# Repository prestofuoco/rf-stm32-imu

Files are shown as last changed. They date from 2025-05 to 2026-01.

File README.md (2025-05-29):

# rf-stm32-imu
4-layer (sig-gnd-gnd-sig) PCB with STM32F4, ICM20948, NRF24L01, USB-C, and 2.4GHz PCB trace antenna from TI's AN043. USB and RF traces are impedance matched/controlled to 90 ohms and 50 ohms respectively.

Antenna: https://www.ti.com/lit/an/swra117d/swra117d.pdf
<p align="center">
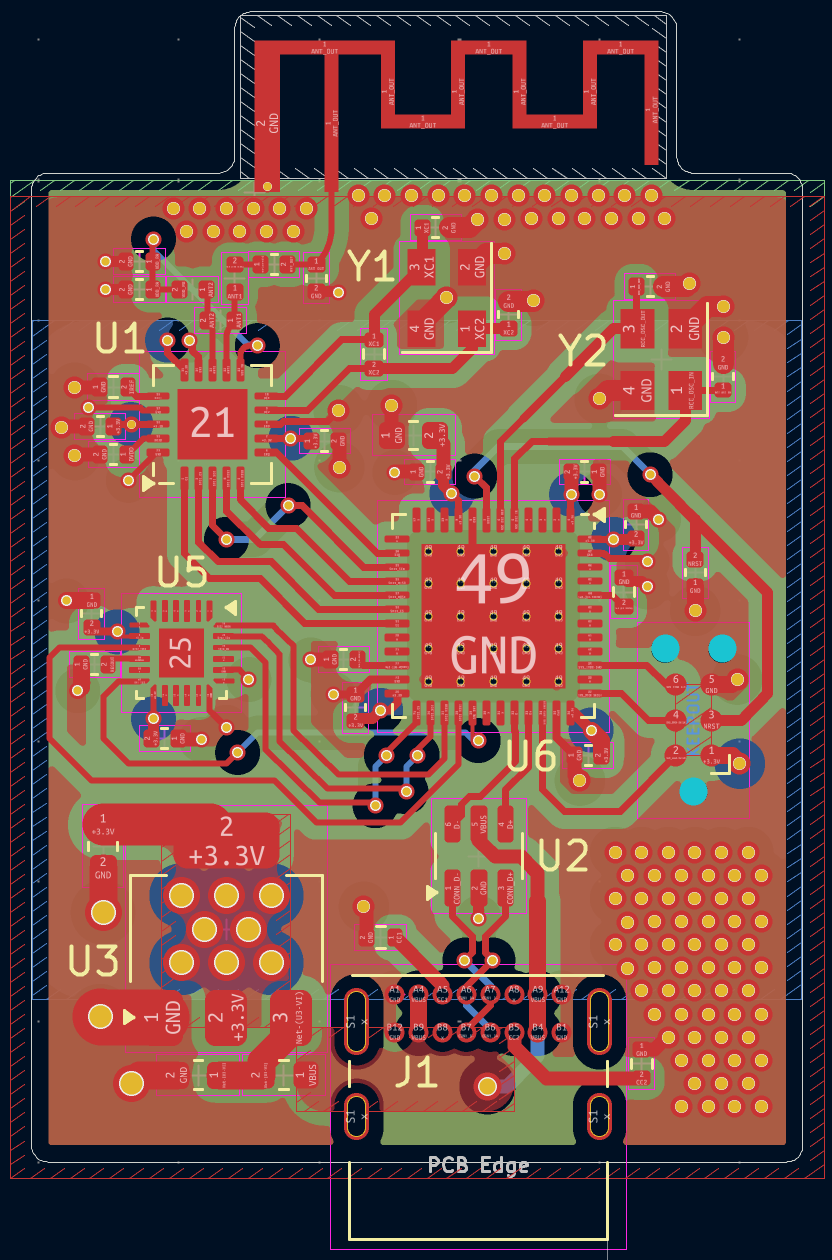
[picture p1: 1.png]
  
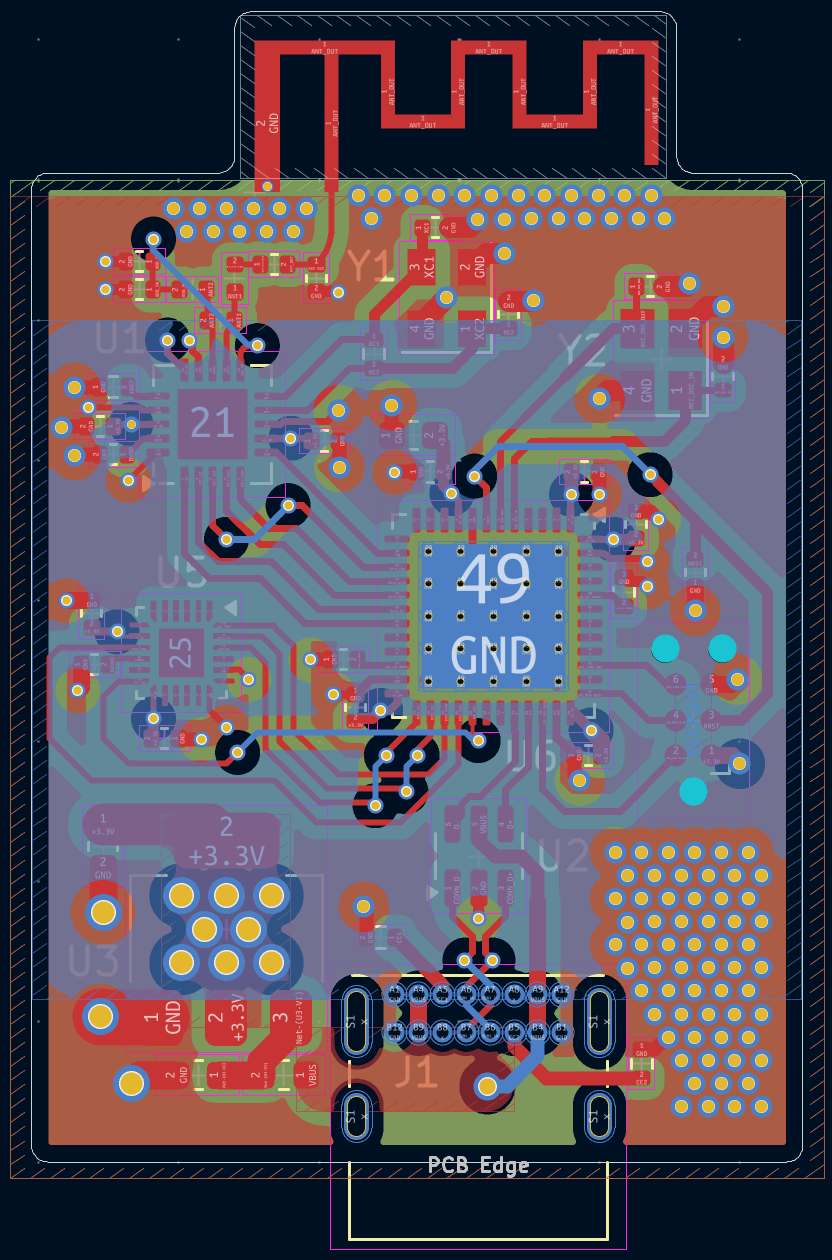
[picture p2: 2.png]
  
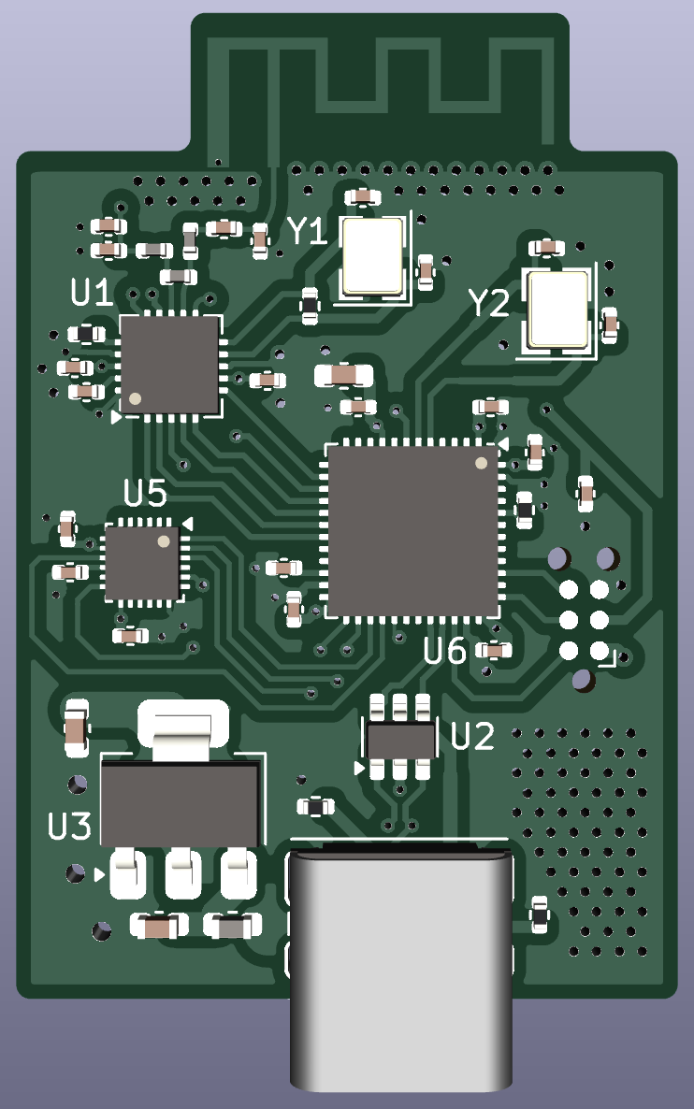
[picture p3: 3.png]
  
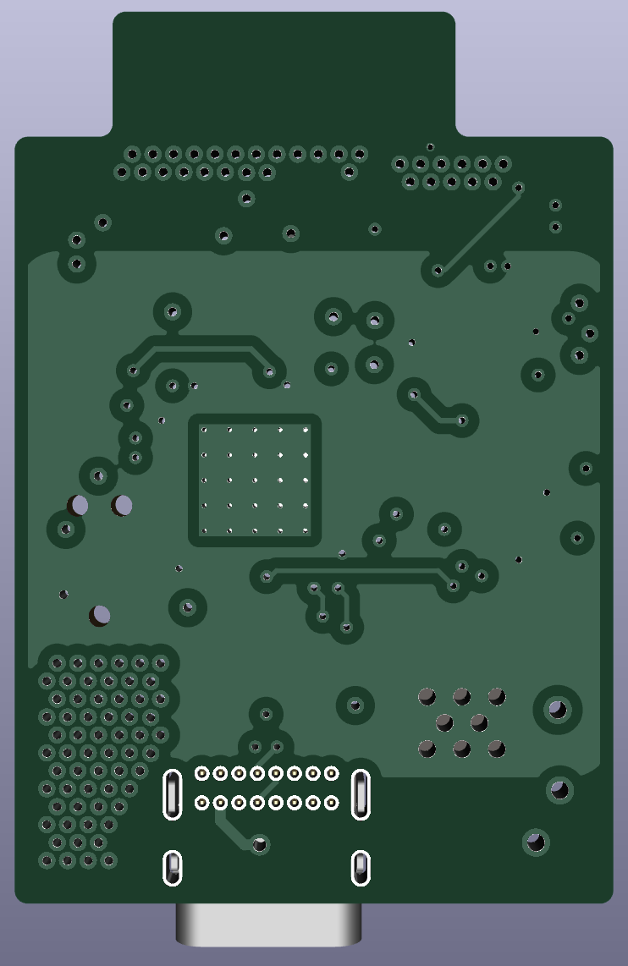
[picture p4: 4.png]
  
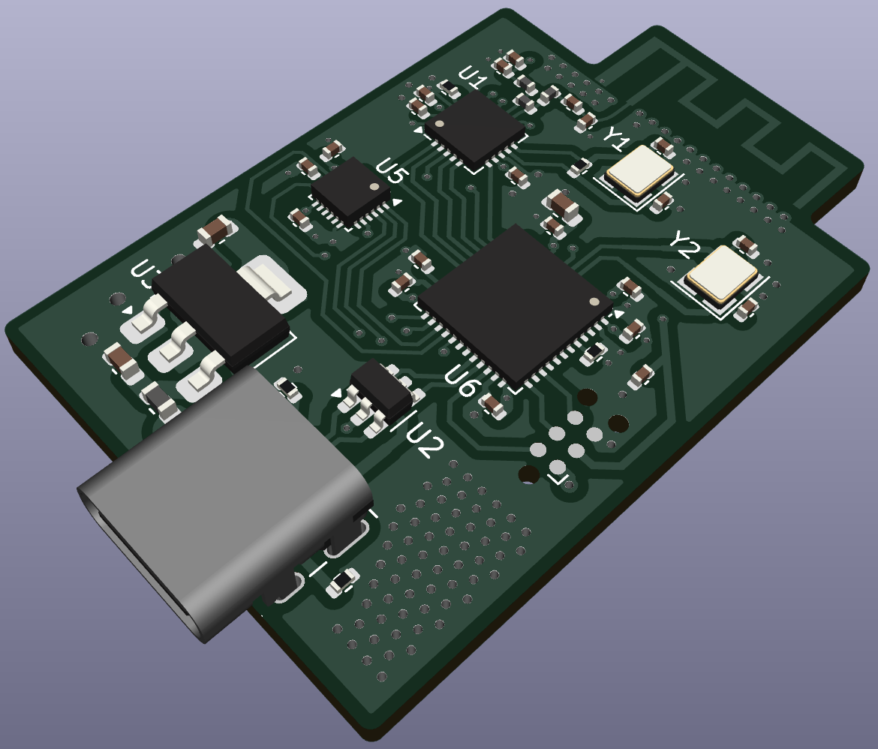
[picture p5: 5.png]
  
</p>

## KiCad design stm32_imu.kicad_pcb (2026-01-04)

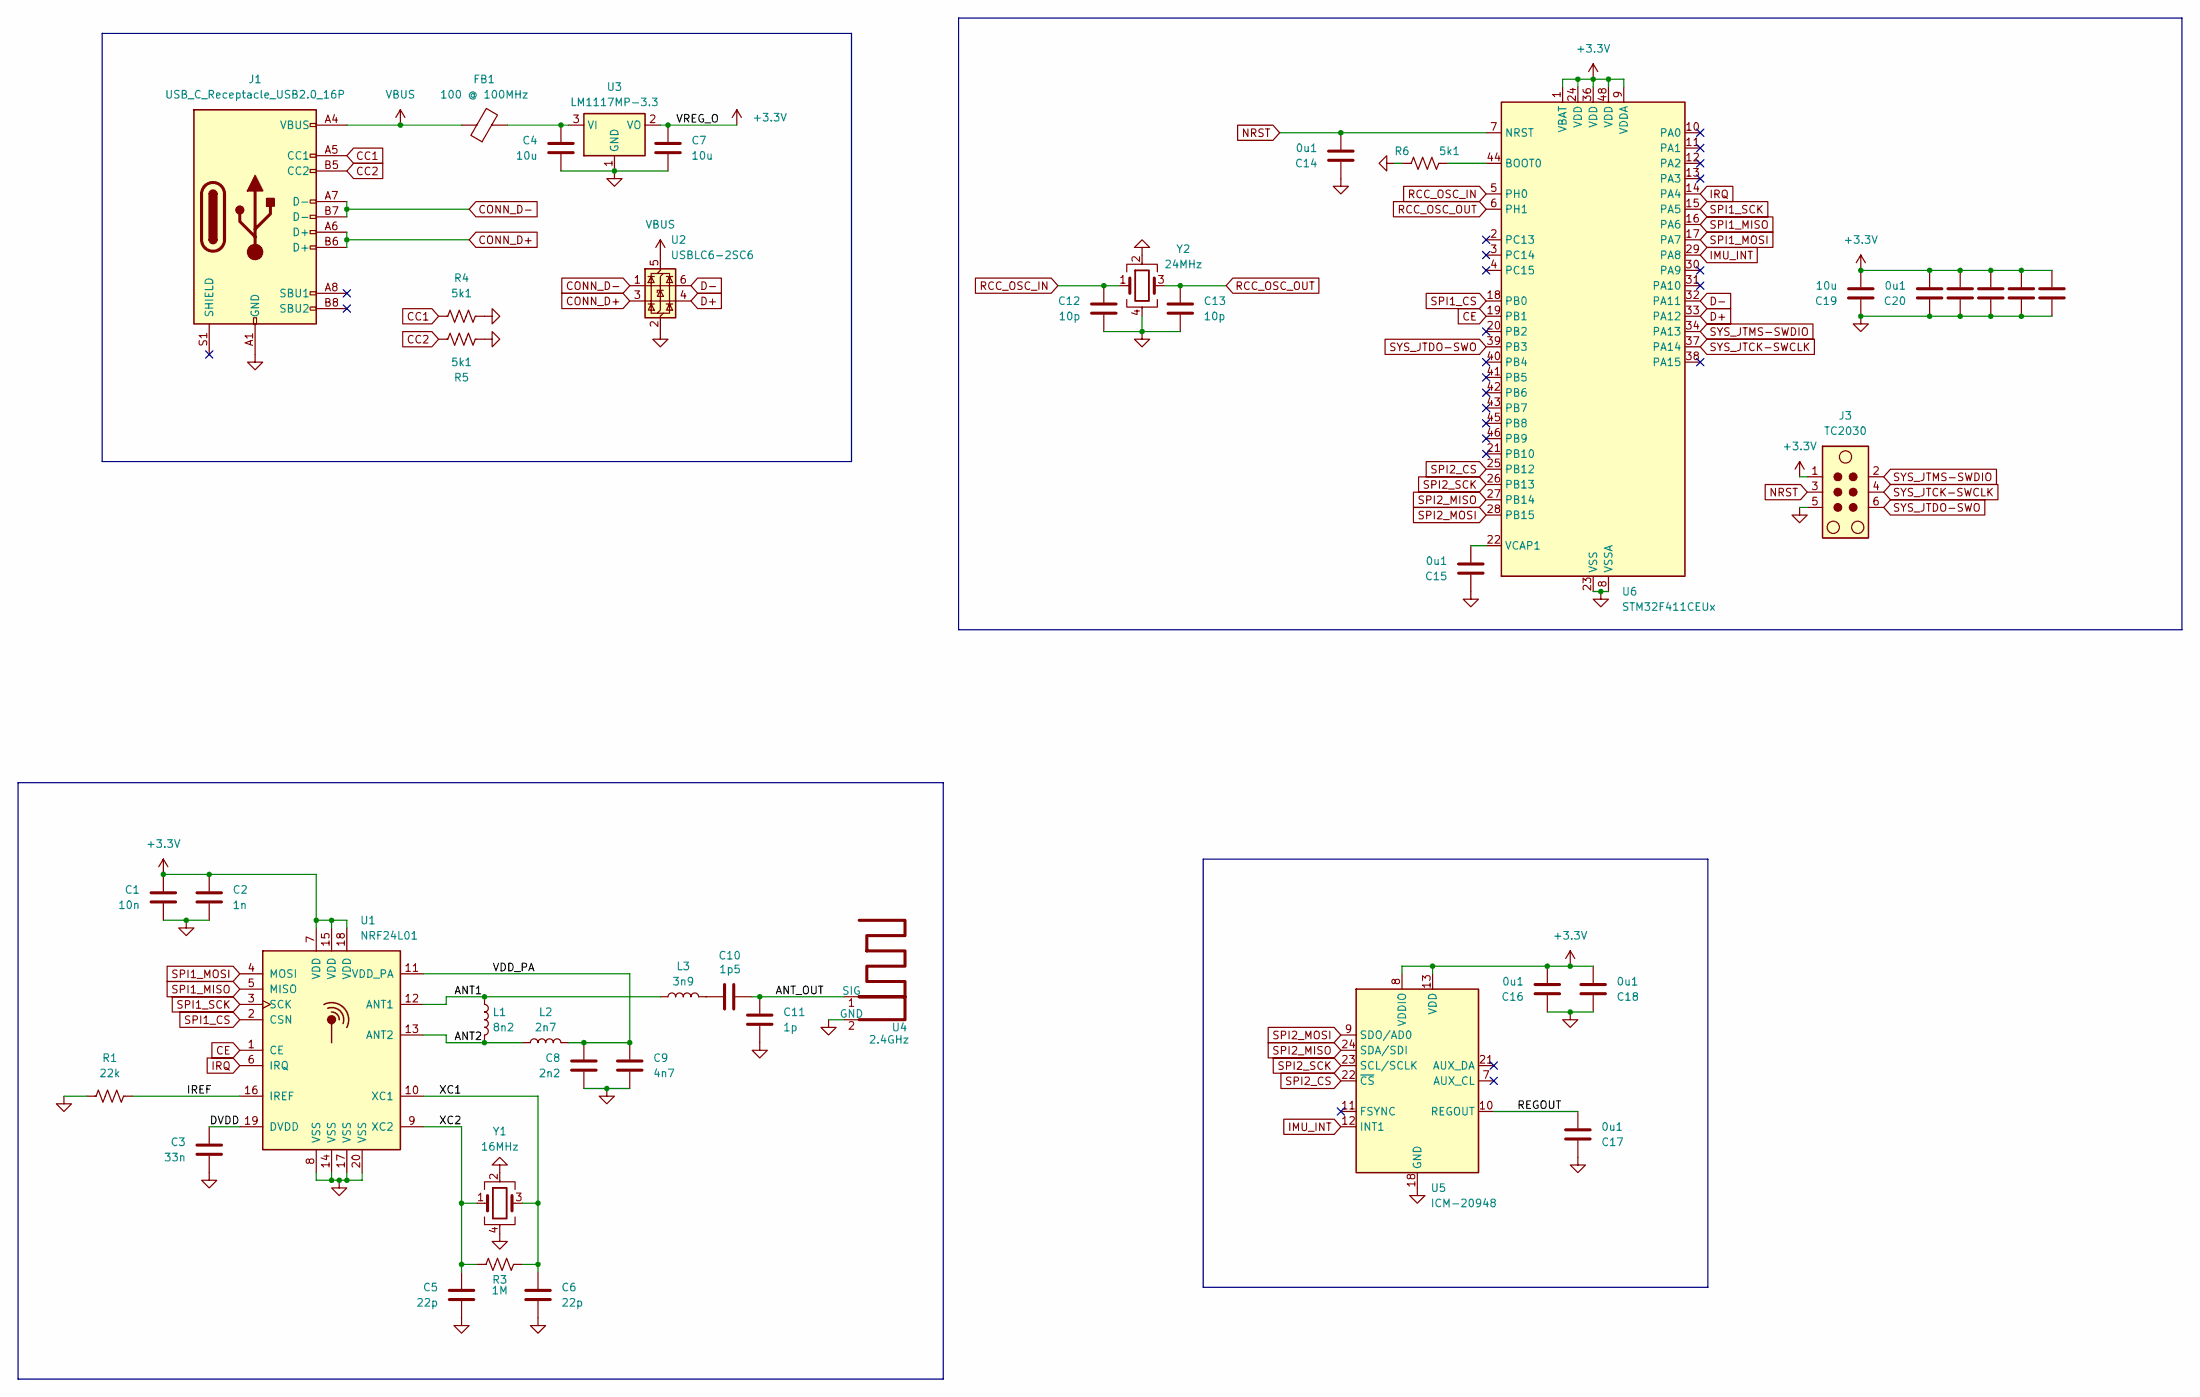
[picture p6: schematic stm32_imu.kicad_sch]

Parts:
C1: 10n; C_0402_1005Metric
C2: 1n; C_0402_1005Metric
C3: 33n; C_0402_1005Metric
C4, C7, C19: 10u; C_0603_1608Metric
C5, C6: 22p; C_0402_1005Metric
C8: 2n2; C_0402_1005Metric
C9: 4n7; C_0402_1005Metric
C10: 1p5; C_0402_1005Metric
C11: 1p; C_0402_1005Metric
C12, C13: 10p; C_0402_1005Metric
C14, C15, C16, C17, C18, C20, C21, C22, C23, C24: 0u1; C_0402_1005Metric
FB1: 100 @ 100MHz; L_0603_1608Metric
J1: USB_C_Receptacle_USB2.0_16P; USB_C_Receptacle_GCT_USB4085
J3: TC2030; Tag-Connect_TC2030-IDC-NL_2x03_P1.27mm_Vertical
L1: 8n2; L_0402_1005Metric
L2: 2n7; L_0402_1005Metric
L3: 3n9; L_0402_1005Metric
R1: 22k; R_0402_1005Metric
R3: 1M; R_0402_1005Metric
R4, R5, R6: 5k1; R_0402_1005Metric
U1: NRF24L01; QFN-20-1EP_4x4mm_P0.5mm_EP2.5x2.5mm
U2: USBLC6-2SC6; SOT-23-6
U3: LM1117MP-3.3; SOT-223-3_TabPin2
U4: 2.4GHz; Untitled
U5: ICM-20948; QFN-24-1EP_3x3mm_P0.4mm_EP1.75x1.6mm
U6: STM32F411CEUx; QFN-48-1EP_7x7mm_P0.5mm_EP5.15x5.15mm_ThermalVias
Y1: 16MHz; Crystal_SMD_EuroQuartz_MT-4Pin_3.2x2.5mm
Y2: 24MHz; Crystal_SMD_Abracon_ABM8G-4Pin_3.2x2.5mm

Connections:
+3.3V: C1.1, C2.1, C7.1, C16.2, C18.2, C19.2, C20.2, C21.2, C22.2, C23.2, C24.2, J3.1, U1.7 (VDD), U1.15 (VDD), U1.18 (VDD), U3.2 (VO), U5.8 (VDDIO), U5.13 (VDD), U6.1 (VBAT), U6.9 (VDDA), U6.24 (VDD), U6.36 (VDD), U6.48 (VDD)
/ANT1: L1.1, L3.1, U1.12 (ANT1)
/ANT2: L1.2, L2.1, U1.13 (ANT2)
/ANT_OUT: C10.2, C11.1, U4.1 (SIG)
/DVDD: C3.1, U1.19 (DVDD)
/IREF: R1.2, U1.16 (IREF)
/REGOUT: C17.2, U5.10 (REGOUT)
/VDD_PA: C8.1, C9.1, L2.2, U1.11 (VDD_PA)
/XC1: C6.1, R3.1, U1.10 (XC1), Y1.3
/XC2: C5.1, R3.2, U1.9 (XC2), Y1.1
CC1: J1.A5 (CC1), R4.1
CC2: J1.B5 (CC2), R5.2
CE: U1.1 (CE), U6.19 (PB1)
CONN_D+: J1.A6 (D+), J1.B6 (D+), U2.3 (I/O2)
CONN_D-: J1.A7 (D-), J1.B7 (D-), U2.1 (I/O1)
D+: U2.4 (I/O2), U6.33 (PA12)
D-: U2.6 (I/O1), U6.32 (PA11)
GND: C1.2, C2.2, C3.2, C4.2, C5.2, C6.2, C7.2, C8.2, C9.2, C11.2, C12.2, C13.2, C14.1, C15.1, C16.1, C17.1, C18.1, C19.1, C20.1, C21.1, C22.1, C23.1, C24.1, J1.A1 (GND), J1.A12 (GND), J1.B1 (GND), J1.B12 (GND), J3.5, R1.1, R4.2, R5.1, R6.1, U1.8 (VSS), U1.14 (VSS), U1.17 (VSS), U1.20 (VSS), U2.2 (GND), U3.1 (GND), U4.2 (GND), U5.18 (GND), U5.20 (GND), U6.8 (VSSA), U6.23 (VSS), U6.35 (VSS), U6.47 (VSS), U6.49 (VSS), Y1.2, Y1.4, Y2.2, Y2.4
IMU_INT: U5.12 (INT1), U6.29 (PA8)
IRQ: U1.6 (IRQ), U6.14 (PA4)
NRST: C14.2, J3.3, U6.7 (NRST)
unnamed: C10.1, L3.2
unnamed: C4.1, FB1.2, U3.3 (VI)
unnamed: R6.2, U6.44 (BOOT0)
unnamed: C15.2, U6.22 (VCAP1)
RCC_OSC_IN: C12.1, U6.5 (PH0), Y2.1
RCC_OSC_OUT: C13.1, U6.6 (PH1), Y2.3
SPI1_CS: U1.2 (CSN), U6.18 (PB0)
SPI1_MISO: U1.5 (MISO), U6.16 (PA6)
SPI1_MOSI: U1.4 (MOSI), U6.17 (PA7)
SPI1_SCK: U1.3 (SCK), U6.15 (PA5)
SPI2_CS: U5.22 (~CS), U6.25 (PB12)
SPI2_MISO: U5.24 (SDA/SDI), U6.27 (PB14)
SPI2_MOSI: U5.9 (SDO/AD0), U6.28 (PB15)
SPI2_SCK: U5.23 (SCL/SCLK), U6.26 (PB13)
SYS_JTCK-SWCLK: J3.4, U6.37 (PA14)
SYS_JTDO-SWO: J3.6, U6.39 (PB3)
SYS_JTMS-SWDIO: J3.2, U6.34 (PA13)
VBUS: FB1.1, J1.A4 (VBUS), J1.A9 (VBUS), J1.B4 (VBUS), J1.B9 (VBUS), U2.5 (VBUS)

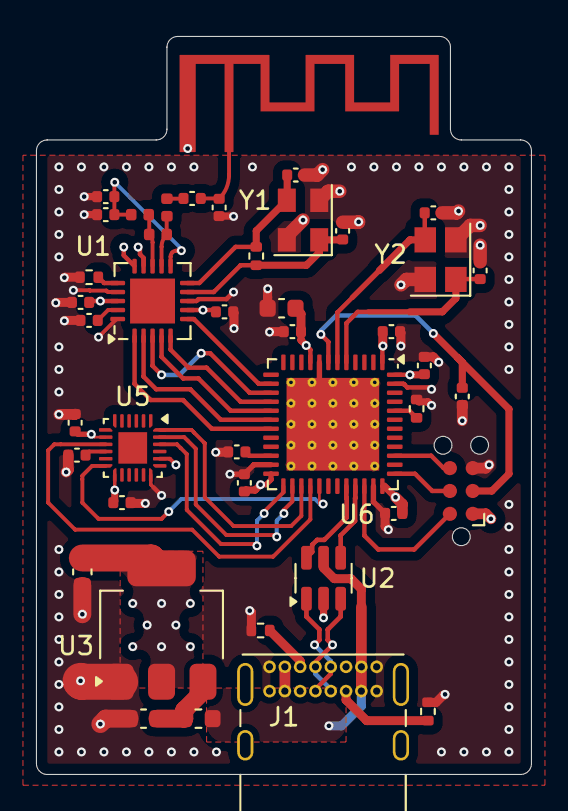
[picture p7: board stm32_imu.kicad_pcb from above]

Board: 4 copper layers, 27.5 x 41.0 mm, 43 parts (0 on the bottom side), 39 nets.
